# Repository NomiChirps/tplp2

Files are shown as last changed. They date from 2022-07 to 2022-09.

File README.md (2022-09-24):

# TPLP2

## Building

Install `bazel` (or `bazelisk`), `gcc-arm-none-eabi`, `arm-none-eabi-newlib`. Developed with `gcc-arm-12.1.0`.

```sh
# debug build
bazel build //tplp:firmware.uf2
# optimized build
bazel build //tplp:firmware.uf2 -c opt

# firmware blob is in bazel-bin
ls -lh bazel-bin/tplp/firmware.uf2
```

## TODO / Notes

- [ ] P1: motor speed pulsates while microstepping. fix this! it's important!
- [ ] don't like the pid algorithm from wikipedia. the proportional term is weird. let's find another one
- [ ] statically allocate all the instances of my hardware classes. we aren't going to be adding a third stepper motor at runtime, you dork.
  - [x] done for StepperMotor
- [ ] Milestone: Paper Tensioning
  - Be able to load paper and feed it forward and backward while maintaining correct tension.
  - [x] needs steppers working
  - [x] needs load cell persistently calibrated & installed
    - [x] save settings button
    - [x] manual calibration gui
    - [x] auto calibrate/zero button (& algorithm)
  - [ ] needs a PID loop with all the accoutrements
    - one loop watches printer roller encoder and controls CENTER of motor target positions
    - one loop watches load cell and controls DIFFERENCE between motor target positions
    - and two MORE loops watch motor target positions and controls motor speeds & directions. maybe those aren't pid though - something about a minimum jerk trajectory? idk.
    - this also means we need to actually install the encoder sooner rather than later.
    - i still want a mathematically sound PID tuning UI. or i guess procedure, if i expose everything in the new params ui.
  - hah, interesting thought... should we use some kind of online state estimation (Kalman filter???) to keep track of the relative radius of the rolls? observe that when moving the rollers at equal but opposite angular velocities, the roll with the greater radius causes the print roller to turn slightly in its direction while tension increases. when the radii are equal, tension would increase while the print roller stays motionless. ... if we can estimate this, would it even be useful? hmmmmmmmmmmmmmmmmmmmmmm
- [ ] I2cController doesn't fail gracefully when a read times out!
- [ ] Create a front panel UI (assignee: wembly :)
  - [ ] runtime stats / logging screen
  - [ ] (later) print status / job control / main screen ?
  - [x] remove the "home" screen, just use that left sidebar for everything. but also hide/delete it when not in use: to free up horizontal space on the screen and to conserve RAM.
  - [x] some kind of display for non-fatal errors. modal dialog box? little icon in the corner to tap on and expand? idk.
    - went with a simple modal
  - [x] manual motor control screen
  - [x] I2C bus scan
  - [x] virtual class interface for callbacks 'n' stuff
  - [x] Use [LVGL](https://lvgl.io)
- [ ] Get peripheral hardware running
  - [ ] Roller encoder
    - neglected to add this to the original hardware design ;(
  - [ ] Laser module (PWM control)
  - [ ] Mirror motor (PWM control; still needs a driver circuit)
  - [ ] Mirror optointerrupter
  - [ ] pinhole photodiode for self-calibration and/or self-test
  - [x] MicroSD card reader
    - we may want two. the one in the display is very difficult to access, so it's more suited to being the internal storage.
    - alternatively, forget using SD cards to upload and go ahead with the wi-fi interface, haha
      - an embedded target and a command-line client tool, in the same project? time for bazel to shine ~
  - [x] Stepper drivers
  - [x] HX711 load cell reader
  - [x] Shiny new front panel display + LVGL driver
  - [x] touchscreen input (SPI breakout)
  - [x] Sharp LCD display + LVGL driver
- [ ] Transfer electronics to a PCB with 12v supply when finalized.
- [ ] loadcell needs its own (shielded?) cable with really good clean connectors that don't jiggle

- 32-bit aligned reads and writes are atomic. It would be nice to take advantage of that and avoid some locking where possible.
  - update: yes indeed, i certainly have been getting sloppy about locking. will i regret it? time will tell.

### Nice to have

- [ ] bring parameter values back and save them in source control at some point. maybe do this automatically somehow (parse the startup log? simple, dirty, works)
- [ ] stepper driver: should coils be set to freewheel (LL) or short-brake (HH) at the top of each command cycle? maybe experiment with it.
- [ ] factory reset button (restoring all params to default, e.g. by deleting the config dir)
- [ ] fatal error handler to display the stack trace on the GUI before crashing
  - will require support from picolog. make sure picolog prevents the crashed task from proceeding, and has a watchdog or something to finish crashing the device if the fatal error handler doesn't finish in time.
- [ ] audit codebase for portMAX_DELAY, CHECK, etc. and make sure everything that can fail "gracefully", does.
- [ ] JTAG? is that a thing i can do?
- [ ] rename all the lvgl_driver.cc to have distinct module names for VLOG
- [ ] clear the display on boot. the random pixels look kinda cool but...
  - actually, no 'clear' command exists. best we can do is turn off the pixels (command 22h, pp.139), do a full memory write, and turn them back on.
- [ ] TSC2007 lvgl driver should debounce, buffer, and interpolate
- [ ] I2cController needs nonblocking operations, coalescing commands, general TLC
- [ ] hook up tft backlight pin and add an adjustable brightness setting (PWM)
- [ ] fix "bazel test //..." by adding target_compatible_with where appropriate
  - this may also involve fixing up rules_pico to make correct use of the defines PICO_NO_HARDWARE and PICO_ON_DEVICE
- [ ] generate & examine .map file for the firmware blob
- [ ] use bloaty to find things to trim off the firmware size
  - random forum post recommends copts "-ffunction-sections -fdata-sections" and ldopts "–gc-sections"
- [ ] Vendor all 3rd party libraries
- [ ] split out various things i'm proud of as their own librar(ies)
- [ ] write stress tests for SpiController/I2cController. lotsa tasks, lotsa devices, all hammering away

## Board configuration/pins

### Pinout / Peripherals

See `tplp/tplp_config.h` for pin and GPIO assignments.

| Bus  | Devices |
| ---- | --- |
| SPI0 | - |
| SPI1 | HX8357; SD Card |
| I2C0 | TSC2007 |
| I2C1 | - |

### Stepper driver ribbon cable layout

- Pin 1 (red) - ENA
- Pin 2 - IN1
- Pin 3 - IN2
- Pin 4 - IN3
- Pin 5 - IN4
- Pin 6 - ENB

### Load cell connector

- Pin 1 - Red - E+
- Pin 2 - Black - E-
- Pin 3 - Green - A-
- Pin 4 - White - A+

## Debugging

Note that USB serial stdio is not available while debugging because pico-debug uses the USB port.

### Setup

1. You will need to have the standard GNU autotools/configure/make toolchain installed on your system, for building OpenOCD.
1. Make sure you'll have the appropriate permissions to access the pico-debug CMSIS-DAP USB device; this can be accomplished by adding a [udev rule](https://github.com/openocd-org/openocd/blob/master/contrib/60-openocd.rules) and adding yourself to the `plugdev` group mentioned in that rule (or edit the rule to use a different group).
1. If using Visual Studio Code, install the "Cortex-Debug" extension.
1. If not using Visual Studio Code, build OpenOCD: `cd third_party/openocd; bazel build //:openocd`. This will download and compile the appropriate version of OpenOCD within the Bazel sandbox, leaving the binaries in `third_party/openocd/bazel-bin/external/openocd/openocd/bin/openocd` and the scripts dir in `third_party/openocd/bazel-bin/external/openocd/openocd/share/openocd/scripts`. Isn't it funny how if you say openocd enough times it doesn't sound like a real word anymore?

### To debug under VSCode

See also: https://github.com/majbthrd/pico-debug/blob/master/howto/vscode1.md

1. Put Pico into bootloader mode (reset while holding BOOTSEL).
1. Run the `flash pico-debug` task in VSCode. This downloads a prebuilt pico-debug image and copies it to the device. Pico is now running the debugger on core 1.
1. Build tplp in debug mode by running the `[debug] build` task.
1. Launch the debug configuration in VSCode ("Run and Debug" tab). This is defined in `.vscode/launch.json`. This will also download and build OpenOCD first, if it hasn't already.
1. The program should automatically be loaded onto the Pico and start running in the debugger.
1. You can restart the program freely, but ending the debug session means you'll need to reflash pico-debug to start again.
   In order to make changes and restart, run the `[debug] build` task and then issue the `load` command in the debug console. Wait for the transfer to finish before hitting the Restart button (Ctrl+Shift+F5).

### To debug without IDE support

See also https://github.com/majbthrd/pico-debug/blob/master/howto/openocd.md.

1. Put Pico into bootloader mode (reset while holding BOOTSEL).
1. Run `bazel run //tools:flash-pico-debug`, which downloads a prebuilt [pico-debug](https://github.com/majbthrd/pico-debug) binary and copies it to the device. Pico is now running the debugger on core 1.
1. Start the OpenOCD server: `third_party/openocd/bazel-bin/external/openocd/openocd/bin/openocd -s third_party/openocd/bazel-bin/external/openocd/openocd/bin/openocd -f interface/cmsis-dap.cfg -f target/rp2040-core0.cfg -c "transport select swd" -c "adapter speed 4000"`. It should connect to the Pico and wait for commands.
1. Build tplp in debug mode: `bazel build --config=picodebug //tplp:firmware.elf`
1. Start GDB: `arm-none-eabi-gdb bazel-bin/tplp/firmware.elf`.
1. Connect GDB to OpenOCD: `(gdb) target remote localhost:3333`.
1. Load the target into flash: `(gdb) load`.
1. Start it: `(gdb) monitor reset init`, `(gdb) continue`.

## Reference Materials

- [RP2040 Datasheet](https://datasheets.raspberrypi.com/rp2040/rp2040-datasheet.pdf) (the good stuff)
- [Raspberry Pi Pico SDK PDF docs](https://datasheets.raspberrypi.com/pico/raspberry-pi-pico-c-sdk.pdf) (more info than the HTML version)
- [Raspberry Pi Pico SDK HTML docs](https://raspberrypi.github.io/pico-sdk-doxygen/) (bare API reference)
- [Raspberry Pi Pico Datasheet](https://datasheets.raspberrypi.com/pico/pico-datasheet.pdf)
- [Getting started with Raspberry Pi Pico](https://datasheets.raspberrypi.com/pico/getting-started-with-pico.pdf)
- [What is the proper way to debounce a GPIO input?](https://raspberrypi.stackexchange.com/questions/118349/what-is-the-proper-way-to-debounce-a-gpio-input)
- [Hardware Design with the RP2040](https://www.mouser.com/pdfDocs/hardware-design-with-rp2040.pdf)
- [FreeRTOS Kernel Quick Start Guide](https://www.freertos.org/FreeRTOS-quick-start-guide.html)
- [FreeRTOS RP2040 SMP demos](https://www.freertos.org/smp-demos-for-the-raspberry-pi-pico-board.html)
- [Use Arduino Libraries with the Rasperry Pi Pico C/C++ SDK](https://www.hackster.io/fhdm-dev/use-arduino-libraries-with-the-rasperry-pi-pico-c-c-sdk-eff55c)
- [How to define and measure clock jitter](https://www.sitime.com/api/gated/AN10007-Jitter-and-measurement.pdf)
- [Bit Twiddling Hacks](http://graphics.stanford.edu/~seander/bithacks.html) (the one and only)

## todos whomst done

- [x] P0: finish making my type-safe fixpoint thing so i can implement the PROPERLY discretized pid algorithm from wikipedia
- [x] redesign manual stepper control UI to match the new API and to be easier to use
- [x] **P1: fix major stepper glitch when reversing direction**
- [x] P1: Okay we REALLY need to be able to dial the motor speed ALL the way down right next to zero. the pid loop is not happy otherwise.
- [x] FIXME: go through all my uses of __not_in_flash and add asserts to make sure they're actually doing that thing (addr < 0x1000000)
- [x] stepper timer interrupt isn't doing the right thing w.r.t. rearming the alarm. fix that. maybe make a template from the impl in paper_controller.
- [x] (!!!) steppers need to be able to go slower! a lot slower!
  - When hz is below the threshold, switch from DMA timer + DREQ to a timer interrupt (high priority, probably?)
- [x] Clean up the prototype electronics
  - [x] remember to power pico thru VSYS, not VBUS, to avoid potentially sending power upstream to the usb host
  - [x] supply 5V to HX711
  - [x] Add bus capacitors
- [x] fix all instances of std::setw(). it only sticks for one output field...
- [x] Begin() Setup() Init(), **PICK ONE**
- [x] UX Improvements
  - [x] fix everything in the ui being scrollable
  - [x] numeric display of load cell value & raw value
  - [x] oops changed my mind about the load cell units. they're actually completely arbitrary.
- [x] need a thingy for persistently saving global parameters / preferences / whatever you wanna call em.
- [x] alright fine let's get StrCat in here sheeeeesh
- [x] SpiController could use improvement - we're not getting full utilization of the bus
  - verdict: use the new DmaController with nonblocking operations where possible, and that's gonna be good enough.
- [x] Load cell time!
  - [x] hx711 pio driver
  - [x] gui for monitoring & calibration
  - [x] print some brackets to calibrate it against my digital scale
- [x] put the load cell period (100ms) in constants.h
- [x] read about the hardware interpolators in rp2040
  - does what it says on the tin. good for linear scaling, affine texture mapping, that kinda thing.
- [x] Mission: DMA 9000
  - see new ideas in tplp/bus/dma.h !!!
  - SpiController needs to take advantage of the new Action stuff to be more nonblocking, and actually make use of the DmaManager queue.
    - to manage CS easily we might need before-Actions as well as after-Actions!
  - I2cController needs... uh... idk i don't want to look at it right now
  - after action report: the new ideas in tplp/bus/dma.h were waaaay too complicated and not actually a performance improvement. went back to the now-current implementation and fixed up SpiController/I2cController to take advantage of its async features.
    - I NEVER WANT TO LOOK AT DMA AGAIN >:(
- [x] Install jumpers on the stepper drivers (to configure internal 5v power supply)
- [x] figure out who's allowed to call xTaskCreate. centralize it.
- [x] forget the std::duration stuff.. really not worth the hassle.
- [x] rename SpiManager -> SpiController
- [x] insert appropriate delays in TSC2007 read cycle; we have noise problems
- [x] consider removing all deletions of FreeRTOS objects and switching to heap_1
  - I considered it. it's not gonna happen
- [x] move/redirect config headers to a config/ dir
- [x] (?!) display fails self-test during startup if usb-serial output not present
  - the issue was it needed some time to boot up after poweron before accepting commands
- [x] LVGL driver for HX8357
- [x] HX8357 self test :)
- [x] rework SpiController again again; it should be able to suport full duplex. instead of sendevent/receiveevent, let's have transferevent(naming???) which specifies optionally both buffers. I GUESS???? if both are specified, they would necessarily have to be the same length!
- [x] get a compile_commands going for //simulator
- [x] have FreeRTOS and LVGL running together in a simulator mode on the host, for UI development (and unit testing?!)
- [x] fix lvgl+simulator so it doesn't build SDL2 twice
- [x] it is time to reorganize the directory structure again
  - we've got /openocd, /lib, /picolog, /tplp... too many different kinds of things at the top level
- [x] bazel build for OpenOCD binary!
- [x] WONTFIX: run blaze with layering_check; but need to do it on Linux because it requires CC=clang. might also need to add clang support to rules_pico.
  - this definitely isn't gonna happen. it needs support from the toolchain definition and i don't want to research how to implement that.
- [x] fix compile_commands extraction, again (problem with lvgl build? maybe strip_include_prefix works correctly on Linux?)
- [x] Why are we spending so much time in Tmr Svc?
  - it's actually not that much time now, without SMP.
- [x] please let's replace tplp_assert() with CHECK(), CHECK_NOTNULL(), etc. likewise DebugLog() -> LOG(INFO), VLOG(1), etc.
  - Implemented "picolog" and broke it out into a library :)
- [x] switch to Linux because wow gosh heckie does windows suck for this kind of development
- [x] create a lint.sh or something. to cover cc and bzl files (using Trunk vscode extension)
- [x] spend a week fruitlessly debugging instability between FreeRTOS-SMP + pico-sdk before giving up on SMP in disgust. at least I learned a lot and ironed out a few other issues along the way.
- [x] vApplicationGetIdleTaskMemory mystery: why doesn't my definition clash with the rp2040 port's in idle_task_static_memory.c?
  - ah. because i needed alwayslink=1 in FreeRTOS. it's fine though, we don't need to add it. the local definition gets linked in just fine.
- [x] (vanity) rename FreeRTOS or FreeRTOS-Kernel to the same thing, so we can say e.g. "@FreeRTOS" instead of "@FreeRTOS-Kernel//:FreeRTOS"
- [x] Tune FreeRTOS
  - The verdict: we'll be using non-SMP with preemption. If we need the second core for something, we'll put it there manually.
  - [x] enable SMP/multicore
    - turns out this was a terrible idea.
  - [x] audit FreeRTOSConfig.h
  - [x] (friendship ended with Arduino) audit Arduino compat libraries for blocking delays?
  - [x] (friendship ended with Arduino) use scope to verify reliability in the presence of Arduino libs
  - [x] write configASSERT handler (use the NeoPixel LED?)
- [x] use the genrule() trick to finally encapsulate FreeRTOS headers
- [x] use DMA for the Sharp LCD driver, just for funsies
- [x] figure out how to track TODO/FIXME/XXX in IDE
- [x] organize source code under src/ (I changed my mind later)
- [x] (it's not possible, i decided) refer to FreeRTOS headers with a prefix, if possible (actually it is)
- [x] Make sure we're not using floating point math anywhere (including dependencies): discovered via std::unordered_map that we panic if any floating point math is used
- [x] Reset to the bootloader without touching the board: magic 1200 baud connection
- [x] Get FreeRTOS running
- [x] Bazel-ify the build

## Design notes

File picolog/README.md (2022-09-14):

# Picolog

Experimental, ambitiously-named [glog-style](https://github.com/google/glog) C++ logging library for the Raspberry Pi Pico under gcc + pico-sdk + FreeRTOS.

Logs are collected in a FreeRTOS queue and flushed to the output asynchronously; unless the FreeRTOS scheduler hasn't been started yet, in which case they are processed immediately.

Not tested with FreeRTOS-SMP or with pico_multicore.

Add the `-mpoke-function-name` compiler flag to get function names in the backtrace for fatal errors.

## Wishlist

- [ ] okay it might be time to move the non-logging ABSL ripoff stuff to somewhere else? or just consider it a PORT of parts of absl??
- [ ] LOG_EVERY
- [ ] track the maximum timestamp as logs are flushed, and make it visually obvious if it ever goes backwards (due to a task being interrupted while logging)
- [ ] arena storage for the non-inlined StatusRep. or maybe we can get rid of it and require that the message be a compile-time constant...? or even better, provide a special case to make that path alloc-free.
- Maybe have a separate task handling FATAL errors so it can be given the highest priority.
- [ ] arena storage for LogMessageData to avoid malloc (still requires mutex)
- [ ] DCHECK
- [ ] LOG level toggles at runtime, maybe per-task and/or per-module
- [ ] ^-- leads to: unit/etc tests
- [ ] Trap hard faults so we can get stack traces for a nullptr dereference :)
  - https://github.com/yocto-8/yocto-8/blob/main/src/arch/pico/extmem/faulthandler.cpp#L12
  - https://forums.raspberrypi.com/viewtopic.php?t=318745
- [ ] support other log targets than stdout, e.g. flash, sd, or custom.
- [x] StatusOr
- [x] support immediate logging before the FreeRTOS scheduler starts
- [x] soften the hard dependency on pico-sdk, so we can run tests and use it in the simulator, with FreeRTOS's posix port
- [x] Status object and CHECK_OK
- [x] per-file VLOG toggles at compile time (use a constexpr function for string comparison with `__FILE__`, probably)
- [x] test for VLOG_IS_ON

## Hard Fault recovery, maybe

See section B1.5.6 of the ARMv6-M reference manual.

When pushing context to the stack, the hardware saves eight 32-bit words, comprising xPSR, ReturnAddress(), LR(R14), R12, R3, R2, R1, and R0.

B1.5.8 Exception return behavior
| EXC_RETURN | Behavior |
| - | - |
| 0xFFFFFFF1 | Return to Handler Mode. Exception return gets state from the Main stack. On return execution uses the Main Stack. |
| 0xFFFFFFF9 | Return to Thread Mode. Exception return gets state from the Main stack. On return execution uses the Main Stack. |
| 0xFFFFFFFD | Return to Thread Mode. Exception return gets state from the Process stack. On return execution uses the Process Stack. |

In the case of a memory fault when recovering the xPSR, if the EXC_RETURN value indicates that the exception return:

- must use the Main stack, SP_main, a lockup at HardFault priority occurs.
- must use the Process stack, SP_process, a Pending HardFault exception is generated

hmmmm

- what is xPSR?
- exception return operation checks SCR.SLEEPONEXIT
- pg. 200 is the handler pseudocode we must satisfy in order to restore into a normal stack
- also check out the freertos rp2040 port implementation!! maybe we can crib most of it off that.

"In ARMv6-M, faults are considered fatal. The only fault status information provided on entry to the HardFault
handler is the EXC_RETURN value, that indicates whether the fault originated from Thread or Handler mode. The
fault handler returns according to the rules defined in ReturnAddress(), see Exception entry behavior on
page B1-196 for details"

"While ARMv6-M does not provide
fault status information to the HardFault handler, it does permit the handler to perform an exception return and
continue execution, in cases where software has the ability to recover from the fault situation"

" Setting the AIRCR.SYSRESETREQ control bit to 1 requests a reset by an
external system resource. The system components that are reset by this request are IMPLEMENTATION DEFINED. A
Local reset is required as part of a system reset request.
Setting the SYSRESETREQ bit to 1 does not guarantee that the reset takes place immediately. A typical code
sequence to synchronize reset following a write to the relevant control bit is:"

```asm
     DSB;
Loop B Loop;
```

-> Could we have the task jump from the faulting instruction to a different function instead? One that calls vTaskSuspend(nullptr) forever. See: vPortStartFirstTask().

http://fastbitlab.com/free-rtos/ has some hints.

## Acknowledgements

Portions of this code are derived from the ABSL library under the terms of the [Apache 2.0 license](https://www.apache.org/licenses/LICENSE-2.0).

```legalese
Copyright 2020 The Abseil Authors.

Licensed under the Apache License, Version 2.0 (the "License");
you may not use this file except in compliance with the License.
You may obtain a copy of the License at

     https://www.apache.org/licenses/LICENSE-2.0

Unless required by applicable law or agreed to in writing, software
distributed under the License is distributed on an "AS IS" BASIS,
WITHOUT WARRANTIES OR CONDITIONS OF ANY KIND, either express or implied.
See the License for the specific language governing permissions and
limitations under the License.
```

Portions of this code are derived from Google's glog library, the license notice of which is reproduced below:

```legalese
Copyright (c) 2008, Google Inc.
All rights reserved.

Redistribution and use in source and binary forms, with or without
modification, are permitted provided that the following conditions are
met:

    * Redistributions of source code must retain the above copyright
notice, this list of conditions and the following disclaimer.
    * Redistributions in binary form must reproduce the above
copyright notice, this list of conditions and the following disclaimer
in the documentation and/or other materials provided with the
distribution.
    * Neither the name of Google Inc. nor the names of its
contributors may be used to endorse or promote products derived from
this software without specific prior written permission.

THIS SOFTWARE IS PROVIDED BY THE COPYRIGHT HOLDERS AND CONTRIBUTORS
"AS IS" AND ANY EXPRESS OR IMPLIED WARRANTIES, INCLUDING, BUT NOT
LIMITED TO, THE IMPLIED WARRANTIES OF MERCHANTABILITY AND FITNESS FOR
A PARTICULAR PURPOSE ARE DISCLAIMED. IN NO EVENT SHALL THE COPYRIGHT
OWNER OR CONTRIBUTORS BE LIABLE FOR ANY DIRECT, INDIRECT, INCIDENTAL,
SPECIAL, EXEMPLARY, OR CONSEQUENTIAL DAMAGES (INCLUDING, BUT NOT
LIMITED TO, PROCUREMENT OF SUBSTITUTE GOODS OR SERVICES; LOSS OF USE,
DATA, OR PROFITS; OR BUSINESS INTERRUPTION) HOWEVER CAUSED AND ON ANY
THEORY OF LIABILITY, WHETHER IN CONTRACT, STRICT LIABILITY, OR TORT
(INCLUDING NEGLIGENCE OR OTHERWISE) ARISING IN ANY WAY OUT OF THE USE
OF THIS SOFTWARE, EVEN IF ADVISED OF THE POSSIBILITY OF SUCH DAMAGE.
```

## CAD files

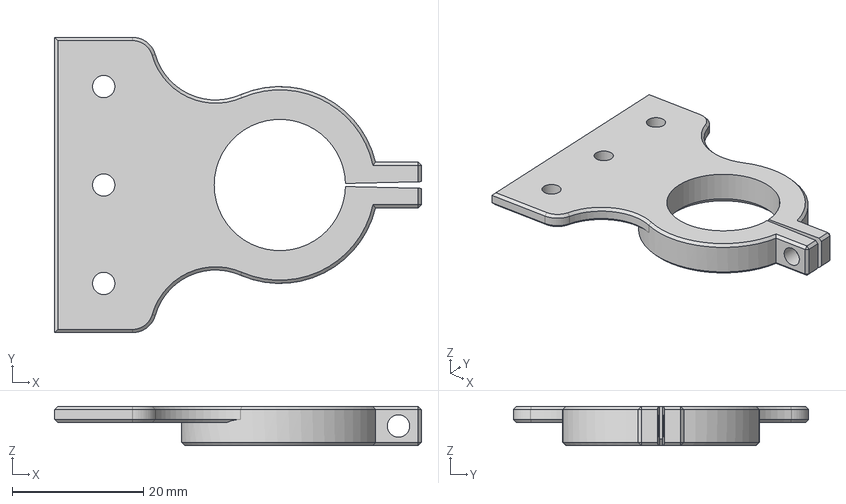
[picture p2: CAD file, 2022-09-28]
cad/Encoder mount v4.step
55.9 x 45.0 x 6.00 mm

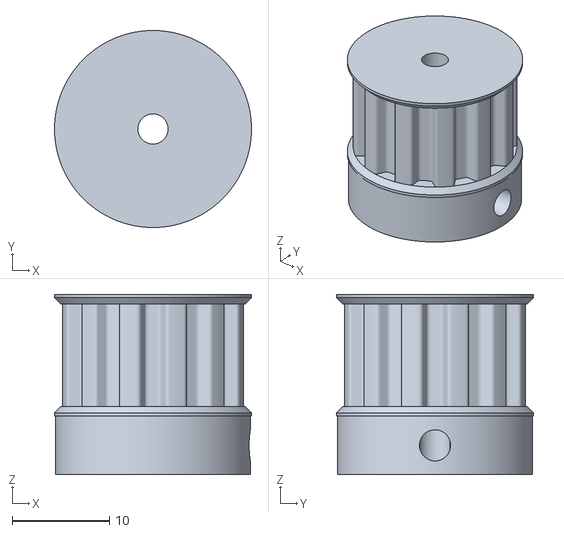
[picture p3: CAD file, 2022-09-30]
cad/pulleys/dcmotor-12.stl
20.2 x 20.2 x 18.5

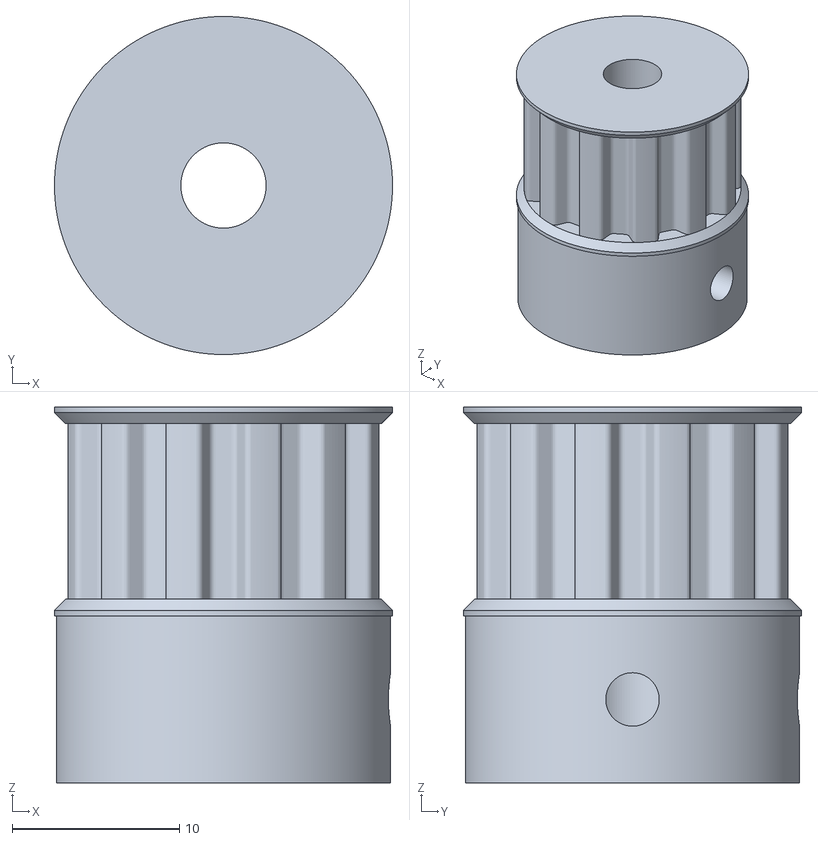
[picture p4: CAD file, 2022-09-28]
cad/pulleys/steppermotor-12.stl
20.2 x 20.2 x 22.5

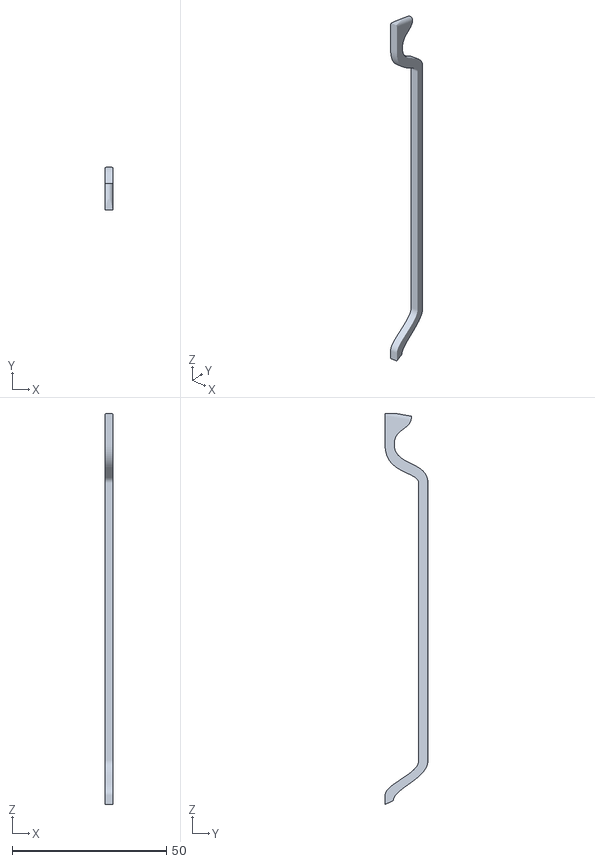
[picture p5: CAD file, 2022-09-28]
cad/spool rib.stl
2.60 x 13.9 x 126.8

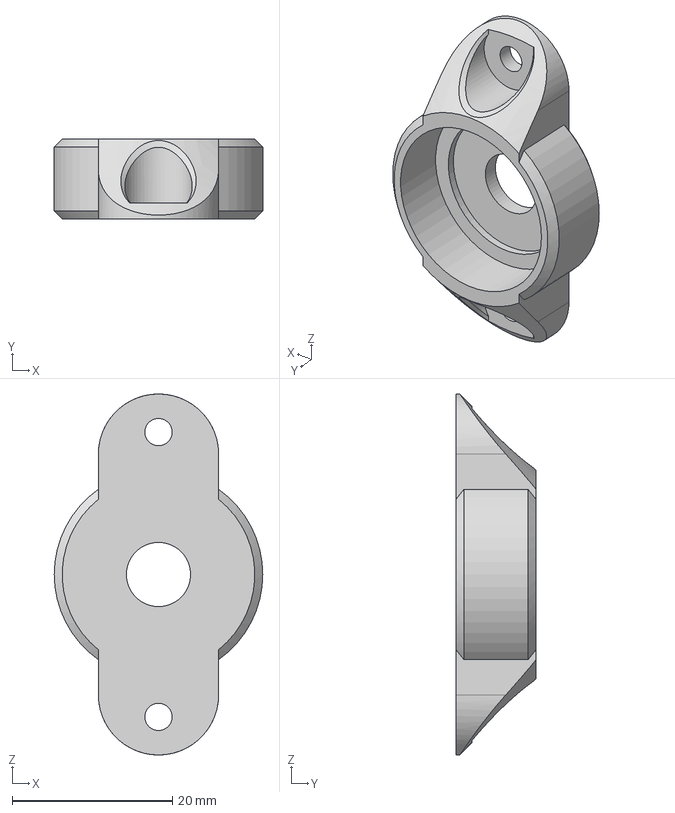
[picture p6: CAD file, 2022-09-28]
cad/bearing seat 608 v3.step
26.0 x 10.0 x 45.0 mm

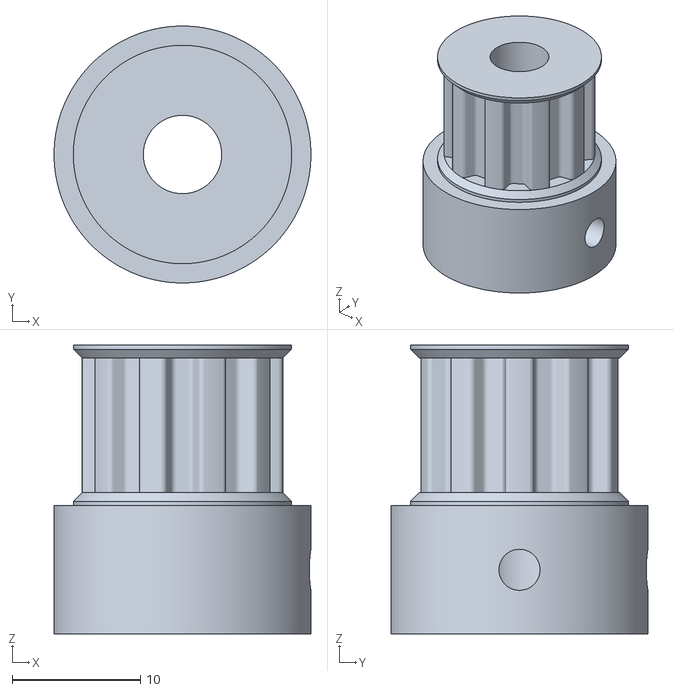
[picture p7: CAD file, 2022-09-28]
cad/pulleys/encoder-10.stl
20.0 x 20.0 x 22.5

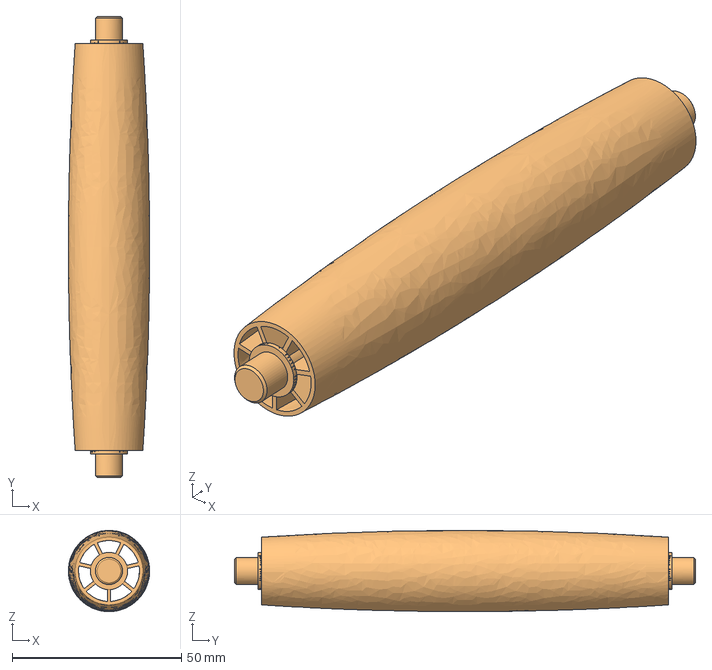
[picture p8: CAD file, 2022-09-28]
cad/guide roller v7.step
24.0 x 136.0 x 24.0 mm
bearing pin 608 x 2

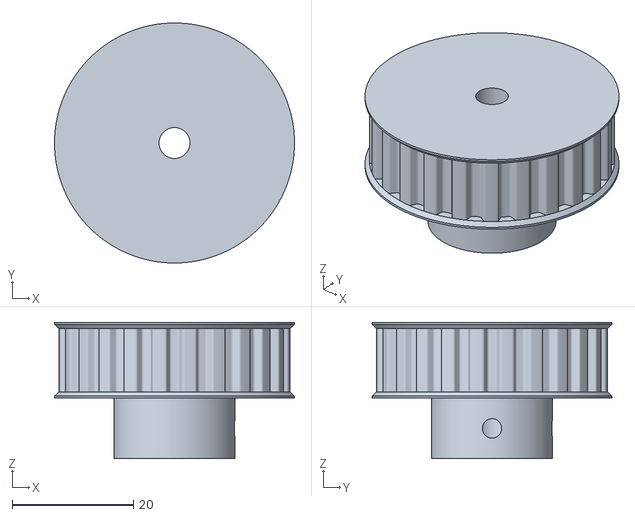
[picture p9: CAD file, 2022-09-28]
cad/pulleys/steppermotor-24.stl
39.6 x 39.6 x 22.5

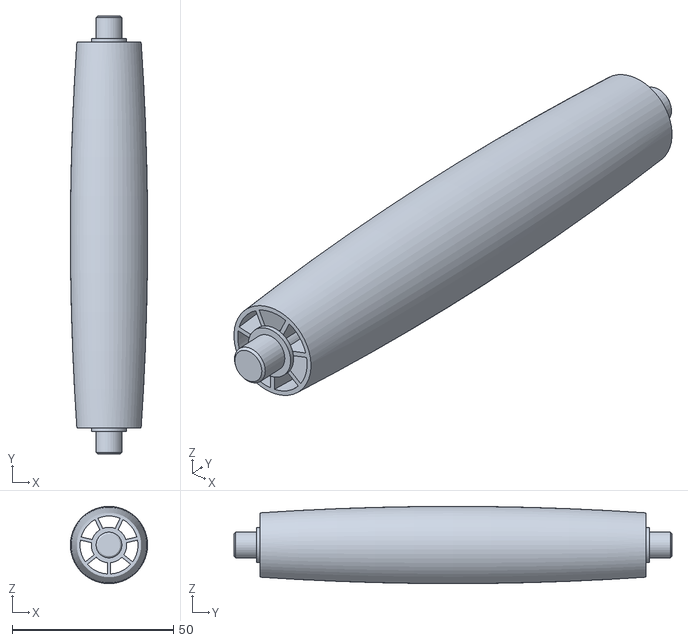
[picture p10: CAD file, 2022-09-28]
cad/guide roller.stl
24.0 x 136.0 x 24.0

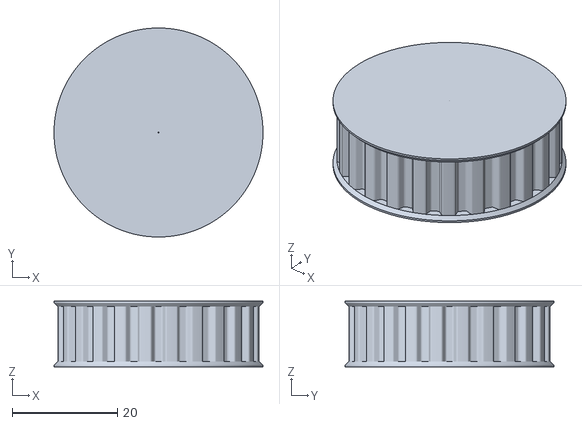
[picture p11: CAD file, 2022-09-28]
cad/pulleys/bare-24.stl
39.6 x 39.6 x 12.5

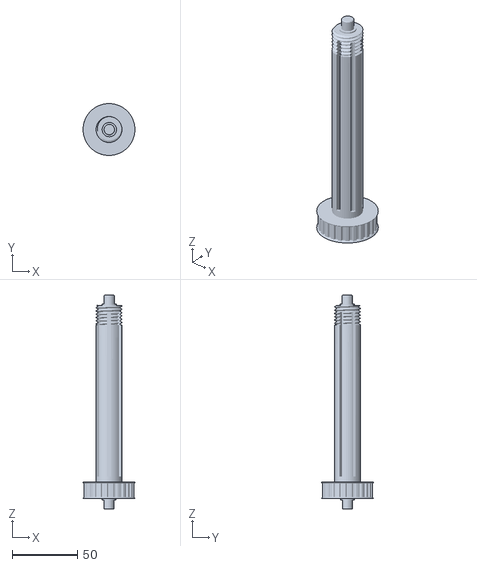
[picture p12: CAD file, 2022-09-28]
cad/spool body.stl
39.6 x 39.6 x 163.5

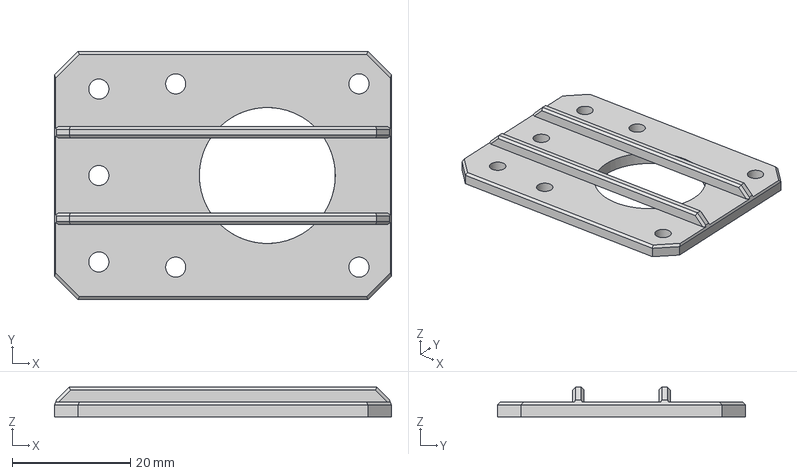
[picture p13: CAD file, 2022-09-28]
cad/Stepper mount v3.step
57.0 x 42.0 x 5.00 mm

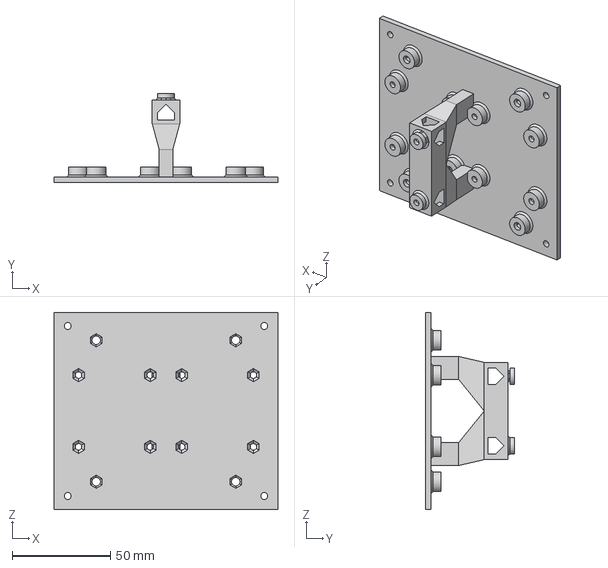
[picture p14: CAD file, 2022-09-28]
cad/stepper driver enclosure v4.step
114.0 x 45.5 x 100.5 mm

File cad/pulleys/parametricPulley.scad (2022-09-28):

// Parametric Pulley with multiple belt profiles
// by droftarts January 2012
// updated and changed by Oscar January 2018 (https://www.thingiverse.com/0scar/about)

// Based on pulleys by:
// http://www.thingiverse.com/thing:11256 by me!
// https://github.com/prusajr/PrusaMendel by Josef Prusa
// http://www.thingiverse.com/thing:3104 by GilesBathgate
// http://www.thingiverse.com/thing:2079 by nophead

// dxf tooth data from http://oem.cadregister.com/asp/PPOW_Entry.asp?company=915217&elementID=07807803/METRIC/URETH/WV0025/F
// pulley diameter checked and modelled from data at http://www.sdp-si.com/D265/HTML/D265T016.html

/**
 * @name Pulley
 * @category Printed
 * @using 1 x m3 nut, normal or nyloc
 * @using 1 x m3x10 set screw or 1 x m3x8 grub screw
 */

// ------------------------
// Idler profile parameters
// ------------------------
number_of_teeth = 60; // [10:100]
profile = 12; // [1:MXL, 2:40DP, 3:XL, 4:H, 5:T2.5, 6:T5, 7:T10, 8:AT5, 9:HTD_3mm, 10:HTD_5mm, 11:HTD_8mm, 12:GT2_2mm, 13:GT2_3mm, 14:GT2_5mm]
motor_shaft_diameter = 8.2; // (in mm)
// Added to the diameter.
motor_shaft_clearance = 0.1;
toothed_part_length = 6.2; // [3:30] (in mm)
base_height = 0; // [0:30] (in mm, 6 is typical)
base_diameter = 20;   // [10:50] (in mm)

// ---------------------------
// Idler & retainer parameters
// ---------------------------
belt_retainer = 1; // [0:No, 1:Yes]
retainer_height_p = 1.0; // [0.5:Tiny (0.5mm), 1:Small (1mm), 1.5:Normal (1.5mm), 2:Big (2mm), 3:Bigger (3mm), 4:Hudge (5mm)]
belt_idler = 1; // [0:No, 1:Yes]
// Height of idler flange over pulley. Set to same as base height if you want an idler but no pulley.
idler_height_p = 1.0; // [0.5:Tiny (0.5mm), 1:Small (1mm), 1.5:Normal (1.5mm), 2:Big (2mm), 3:Bigger (3mm), 4:Hudge (5mm)]

// ---------------
// Shaft fastening
// ---------------
screws_disposition = 3; // [0:None, 1:1 screw, 2:2 screws at 90deg, 3:3 screws at 120deg, 4:4 screws at 90deg]
nut_shape = 1; // [1:Hexagonal, 0:Square]
screw_profile = 4; // [0:M1, 1:M1.6, 2:M2, 3:M2.5, 4:M3, 5:M4, 6:M5, 7:M6]

// Distance between inner face of nut and shaft - can be negative - (in mm).
nut_shaft_distance = 1.2;

// Bolt head shape (0 is inactive) subtracts a bolt head sized hexagon for hexagon bolts
idler_bolt_option = 0; // [0:none, 1:M3, 2:M4, 3:M5, 4:M6, 5:M8, 6:M10, 7:M12, 8:custom] for custom: make changes below!

// Optional metal flange attachment (0 is inactive)
flange_option = 1;
flange_screw_profile = 5; // [0:M1, 1:M1.6, 2:M2, 3:M2.5, 4:M3, 5:M4, 6:M5, 7:M6]
flange_screws_disposition = 4; // [0:None, 1:1 screw, 2:2 screws at 180deg, 3:3 screws at 120deg, 4:4 screws at 90deg]
flange_screwoffset_radius = 26/2;
flange_diam = 32; // Set to zero to disable the flange to be sunk in the idler
flange_thickness = 3; // Set to zero to disable the flange to be sunk in the idler
flange_use_tap = 1; // Diameter is smaller when used for tapping, 0 to larger hole for easy fit


// --------------------------------------------------
// ADVANCED parameters for scaling tooth for good fit
// --------------------------------------------------
// To improve fit of belt to pulley, set the following constant.
// Decrease or increase by 0.1mm at a time. We are modelling the
// *BELT* tooth here, not the tooth on the pulley. Increasing the
// number will *decrease* the pulley tooth size. Increasing the
// tooth width will also scale proportionately the tooth depth,
// to maintain the shape of the tooth, and increase how far into
// the pulley the tooth is indented. Can be negative too!
additional_tooth_width = 0.2; //mm
// If you need more tooth depth than this provides, adjust the
// following constant. However, this will cause the shape of the
// tooth to change.
additional_tooth_depth = 0; //mm

// ------------------------------------
// Calculated parameters (do not alter)
// ------------------------------------
idler_height = (belt_idler==0 ? 0 : idler_height_p);
retainer_height = (belt_retainer==0 ? 0 : retainer_height_p);
//echo (str("Idler height\t= ",idler_height," mm"));
//echo (str("Retainer height\t= ",retainer_height," mm"));
no_of_nuts = screws_disposition;
nut_angle = no_of_nuts != 3 ? 90 : 120;
motor_shaft = motor_shaft_diameter + motor_shaft_clearance;
screw_diameters = [1, 1.6, 2, 2.5, 3, 4, 5, 6];
nut_widths = [2.5, 3.2, 4, 5, 5.5, 7, 8, 10];
nut_depths = [1, 1.3, 1.6, 2, 2.4, 3.2, 4.7, 5.2];
// bolthead size circ.[ none,    M3,    M4,   M5,    M6,    M8,   M10,   M12, custom]
bolt_head_diameters = [0.000, 6.010, 7.660, 8.79, 11.05, 14.38, 17.77, 20.03,  15.8]; // circle diameter, not width across flats!
bolt_head_heights =   [0.000, 2.125, 2.925, 3.65,  4.15,  5.45,  6.58,  7.68,   5.5];
screw_diameter = screw_diameters[screw_profile] + 0.2;
nut_width = nut_widths[screw_profile] + 0.2;
nut_depth = nut_depths[screw_profile] + 0.3;
bolt_head_diam = bolt_head_diameters[idler_bolt_option] + 0.2; // + 0.1-2 for tight fit
bolt_head_height = bolt_head_heights[idler_bolt_option] + 0.2;
screw_hole_sf = flange_use_tap == 1 ? 0.9 : 1.1; // 0.9 is the recommended value for taps of fine thread, 0.85 for coarse threads
flange_screw_diameter = screw_diameters[flange_screw_profile] * screw_hole_sf; 
flange_no_of_screws = flange_screws_disposition;
flange_screw_angle = flange_no_of_screws != 3 ? (flange_no_of_screws == 2 ? 180 : 90) : 120;

// --------------------
// Calculated constants
// --------------------
nut_elevation = base_height/2;
metric_nut_width_across_points = 2*((nut_width/2)/cos(30)); // This is needed for the nut trap
// The following set the pulley diameter for a given number of teeth
MXL_pulley_dia = tooth_spacing (2.032,0.254);
40DP_pulley_dia = tooth_spacing (2.07264,0.1778);
XL_pulley_dia = tooth_spacing (5.08,0.254);
H_pulley_dia = tooth_spacing (9.525,0.381);
T2_5_pulley_dia = tooth_spaceing_curvefit (0.7467,0.796,1.026);
T5_pulley_dia = tooth_spaceing_curvefit (0.6523,1.591,1.064);
T10_pulley_dia = tooth_spacing (10,0.93);
AT5_pulley_dia = tooth_spaceing_curvefit (0.6523,1.591,1.064);
HTD_3mm_pulley_dia = tooth_spacing (3,0.381);
HTD_5mm_pulley_dia = tooth_spacing (5,0.5715);
HTD_8mm_pulley_dia = tooth_spacing (8,0.6858);
GT2_2mm_pulley_dia = tooth_spacing (2,0.254);
GT2_3mm_pulley_dia = tooth_spacing (3,0.381);
GT2_5mm_pulley_dia = tooth_spacing (5,0.5715);
// The following calls the pulley creation part, and passes the pulley diameter and tooth width to that module
if ( profile == 1 ) {pulley("MXL" , MXL_pulley_dia , 0.508 , 1.321 ); }
if ( profile == 2 ) {pulley("40 D.P." , 40DP_pulley_dia , 0.457 , 1.226 ); }
if ( profile == 3 ) {pulley("XL" , XL_pulley_dia , 1.27, 3.051 ); }
if ( profile == 4 ) {pulley("H" , H_pulley_dia ,1.905 , 5.359 ); }
if ( profile == 5 ) {pulley("T2.5" , T2_5_pulley_dia , 0.7 , 1.678 ); }
if ( profile == 6 ) {pulley("T5" , T5_pulley_dia , 1.19 , 3.264 ); }
if ( profile == 7 ) {pulley("T10" , T10_pulley_dia , 2.5 , 6.13 ); }
if ( profile == 8 ) {pulley("AT5" , AT5_pulley_dia , 1.19 , 4.268 ); }
if ( profile == 9 ) {pulley("HTD 3mm" , HTD_3mm_pulley_dia , 1.289 , 2.27 ); }
if ( profile == 10 ){pulley("HTD 5mm" , HTD_5mm_pulley_dia , 2.199 , 3.781 ); }
if ( profile == 11 ){pulley("HTD 8mm" , HTD_8mm_pulley_dia , 3.607 , 6.603 ); }
if ( profile == 12 ){pulley("GT2 2mm" , GT2_2mm_pulley_dia , 0.764 , 1.494 ); }
if ( profile == 13 ){pulley("GT2 3mm" , GT2_3mm_pulley_dia , 1.169 , 2.31 ); }
if ( profile == 14 ){pulley("GT2 5mm" , GT2_5mm_pulley_dia , 1.969 , 3.952 ); }

// ---------
// Functions
// ---------
function tooth_spaceing_curvefit (b,c,d)
  = ((c * pow(number_of_teeth,d)) / (b + pow(number_of_teeth,d))) * number_of_teeth ;

function tooth_spacing(tooth_pitch,pitch_line_offset)
  = (2*((number_of_teeth*tooth_pitch)/(3.14159265*2)-pitch_line_offset)) ;

// ================================================================================
// Main Module
// ================================================================================
module pulley( belt_type , pulley_OD , tooth_depth , tooth_width ){
  echo (str("Belt type = ",belt_type,"; Number of teeth = ",number_of_teeth,"; Pulley Outside Diameter = ",pulley_OD,"mm "));
  tooth_distance_from_centre = sqrt( pow(pulley_OD/2,2) - pow((tooth_width+additional_tooth_width)/2,2));
  tooth_width_scale = (tooth_width + additional_tooth_width ) / tooth_width;
  tooth_depth_scale = ((tooth_depth + additional_tooth_depth ) / tooth_depth) ;

  difference(){   
    translate([0,0,idler_height]){
      union(){
        //base
        if (( base_height < 2 ) && (no_of_nuts > 0)){ 
          if (base_height != 0){
            echo ("CAN'T DRAW PULLEY BASE, HEIGHT LESS THAN 2!!!"); 
          }
        } else {
          translate([0,0,-idler_height]){
            cylinder(d=base_diameter, h=base_height, $fn=base_diameter*20, center=false);
          }
        }
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

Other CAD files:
cad/Encoder mount.stl
cad/pulleys/encoder-12.stl
cad/bearing seat 608.stl
cad/stepper driver enclosure.stl
cad/Stepper mount.stl
cad/spool nut.stl

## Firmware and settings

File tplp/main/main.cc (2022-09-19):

#include <cstdio>

#include "FreeRTOS/FreeRTOS.h"
#include "FreeRTOS/task.h"
#include "tplp/config/hw.h"
#include "tplp/config/tasks.h"
#include "tplp/main/startup.h"

#if LIB_PICO_STDIO_USB
#include "pico/stdio_usb.h"
#endif
#if LIB_PICO_STDIO_UART
#include "hardware/gpio.h"
#include "hardware/timer.h"
#include "pico/stdio_uart.h"
#endif

int main() {
#if LIB_PICO_STDIO_USB
  stdio_usb_init();
#endif
#if LIB_PICO_STDIO_UART
  stdio_uart_init_full(uart0, 115200, tplp::Pins::UART0_TX, -1);
  // Invert UART signal to be compatible with RS232.
  gpio_set_outover(tplp::Pins::UART0_TX, GPIO_OVERRIDE_INVERT);
  busy_wait_ms(100);
#endif

  // TODO: add a build timestamp and version line at bootup
  // printf("tplp2 built %s at %s", TPLP_BUILD_TIMESTAMP, TPLP_VERSION_ID);
  printf("tplp2 boot. TODO: add a build timestamp\n");

  xTaskCreate(&tplp::StartupTask, "STARTUP", tplp::TaskStacks::kStartup,
              nullptr, tplp::TaskPriorities::kStartup, nullptr);
  vTaskStartScheduler();
  panic("scheduler died :(");

  return 1;
}

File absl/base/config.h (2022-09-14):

//
// Copyright 2017 The Abseil Authors.
//
// Licensed under the Apache License, Version 2.0 (the "License");
// you may not use this file except in compliance with the License.
// You may obtain a copy of the License at
//
//      https://www.apache.org/licenses/LICENSE-2.0
//
// Unless required by applicable law or agreed to in writing, software
// distributed under the License is distributed on an "AS IS" BASIS,
// WITHOUT WARRANTIES OR CONDITIONS OF ANY KIND, either express or implied.
// See the License for the specific language governing permissions and
// limitations under the License.
//
// -----------------------------------------------------------------------------
// File: config.h
// -----------------------------------------------------------------------------
//
// This header file defines a set of macros for checking the presence of
// important compiler and platform features. Such macros can be used to
// produce portable code by parameterizing compilation based on the presence or
// lack of a given feature.
//
// We define a "feature" as some interface we wish to program to: for example,
// a library function or system call. A value of `1` indicates support for
// that feature; any other value indicates the feature support is undefined.
//
// Example:
//
// Suppose a programmer wants to write a program that uses the 'mmap()' system
// call. The Abseil macro for that feature (`ABSL_HAVE_MMAP`) allows you to
// selectively include the `mmap.h` header and bracket code using that feature
// in the macro:
//
//   #include "absl/base/config.h"
//
//   #ifdef ABSL_HAVE_MMAP
//   #include "sys/mman.h"
//   #endif  //ABSL_HAVE_MMAP
//
//   ...
//   #ifdef ABSL_HAVE_MMAP
//   void *ptr = mmap(...);
//   ...
//   #endif  // ABSL_HAVE_MMAP

#ifndef ABSL_BASE_CONFIG_H_
#define ABSL_BASE_CONFIG_H_

// Included for the __GLIBC__ macro (or similar macros on other systems).
#include <limits.h>

#ifdef __cplusplus
// Included for __GLIBCXX__, _LIBCPP_VERSION
#include <cstddef>
#endif  // __cplusplus

// ABSL_INTERNAL_CPLUSPLUS_LANG
//
// MSVC does not set the value of __cplusplus correctly, but instead uses
// _MSVC_LANG as a stand-in.
// https://docs.microsoft.com/en-us/cpp/preprocessor/predefined-macros
//
// However, there are reports that MSVC even sets _MSVC_LANG incorrectly at
// times, for example:
// https://github.com/microsoft/vscode-cpptools/issues/1770
// https://reviews.llvm.org/D70996
//
// For this reason, this symbol is considered INTERNAL and code outside of
// Abseil must not use it.
#if defined(_MSVC_LANG)
#define ABSL_INTERNAL_CPLUSPLUS_LANG _MSVC_LANG
#elif defined(__cplusplus)
#define ABSL_INTERNAL_CPLUSPLUS_LANG __cplusplus
#endif

#if defined(__APPLE__)
// Included for TARGET_OS_IPHONE, __IPHONE_OS_VERSION_MIN_REQUIRED,
// __IPHONE_8_0.
#include <Availability.h>
#include <TargetConditionals.h>
#endif

#include "absl/base/options.h"
#include "absl/base/policy_checks.h"

// Abseil long-term support (LTS) releases will define
// `ABSL_LTS_RELEASE_VERSION` to the integer representing the date string of the
// LTS release version, and will define `ABSL_LTS_RELEASE_PATCH_LEVEL` to the
// integer representing the patch-level for that release.
//
// For example, for LTS release version "20300401.2", this would give us
// ABSL_LTS_RELEASE_VERSION == 20300401 && ABSL_LTS_RELEASE_PATCH_LEVEL == 2
//
// These symbols will not be defined in non-LTS code.
//
// Abseil recommends that clients live-at-head. Therefore, if you are using
// these symbols to assert a minimum version requirement, we recommend you do it
// as
//
// #if defined(ABSL_LTS_RELEASE_VERSION) && ABSL_LTS_RELEASE_VERSION < 20300401
// #error Project foo requires Abseil LTS version >= 20300401
// #endif
//
// The `defined(ABSL_LTS_RELEASE_VERSION)` part of the check excludes
// live-at-head clients from the minimum version assertion.
//
// See https://abseil.io/about/releases for more information on Abseil release
// management.
//
// LTS releases can be obtained from
// https://github.com/abseil/abseil-cpp/releases.
#undef ABSL_LTS_RELEASE_VERSION
#undef ABSL_LTS_RELEASE_PATCH_LEVEL

// Helper macro to convert a CPP variable to a string literal.
#define ABSL_INTERNAL_DO_TOKEN_STR(x) #x
#define ABSL_INTERNAL_TOKEN_STR(x) ABSL_INTERNAL_DO_TOKEN_STR(x)

// -----------------------------------------------------------------------------
// Abseil namespace annotations
// -----------------------------------------------------------------------------
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

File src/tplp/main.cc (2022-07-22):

#include <chrono>
#include <cstdio>

#include "FreeRTOS.h"
#include "hardware/gpio.h"
#include "hardware/pio.h"
#include "hardware/spi.h"
#include "pico/bootrom.h"
#include "pico/stdlib.h"
#include "queue.h"
#include "src/lib/SharpLCD/SharpLCD.h"
#include "src/tplp/util.h"
#include "src/tplp/ws2812.h"
#include "task.h"

using std::chrono_literals::operator""ms;

extern "C" {

// FreeRTOS assertion failure handler
void vAssertCalled(const char *const file, unsigned long line) {
  printf("Assertion failed at: %s:%lu\n", file, line);
  // Leave interrupts enabled so we can still get back to the bootloader via
  // the USB serial magic thing.
  for (;;) {
  }
}

void FreeRTOS_ConfigureTimeForRunTimeStats() {}

unsigned long FreeRTOS_GetRunTimeCounterValue() {
  return to_us_since_boot(get_absolute_time());
}
}

namespace tplp {

struct Pins {
  static const uint LCD_CS = 8;
  static const uint SPI_SCLK = 18;
  static const uint SPI_MOSI = 19;
  static const uint NEOPIXEL = 16;
};

void lcd_task(void *) {
  SharpLCD display(spi0, Pins::SPI_SCLK, Pins::SPI_MOSI, Pins::LCD_CS);
  display.Begin();
  display.Clear();
  SharpLCD::FrameBuffer white = display.AllocateNewFrameBuffer();
  SharpLCD::FrameBuffer black = display.AllocateNewFrameBuffer();
  white.Clear(0);
  black.Clear(1);

  TaskHandle_t task = xTaskGetCurrentTaskHandle();
  std::function<void()> ready_isr = [task]() {
    BaseType_t higher_priority_task_woken;
    vTaskNotifyGiveFromISR(task, &higher_priority_task_woken);
    portYIELD_FROM_ISR(higher_priority_task_woken);
  };
  display.SetReadyISR(ready_isr);

  while (true) {
    display.DrawFrameBufferBlocking(white);
    ulTaskNotifyTake(false, portMAX_DELAY);
    display.DrawFrameBufferBlocking(black);
    ulTaskNotifyTake(false, portMAX_DELAY);
  }
}

void led_task(void *) {
  const int LED_PIN = PICO_DEFAULT_LED_PIN;
  gpio_init(LED_PIN);
  gpio_set_dir(LED_PIN, GPIO_OUT);
  while (true) {
    gpio_put(LED_PIN, 1);
    vTaskDelay(as_ticks(200ms));
    gpio_put(LED_PIN, 0);
    vTaskDelay(as_ticks(200ms));
  }
}

void neopixel_task(void *) {
  // ws2812_program_init(PIO pio, uint sm, uint offset, uint pin, float freq,
  // bool rgbw)
}

void button_task(void *) {
  // xQueueReceive(button_queue, void *const pvBuffer, TickType_t xTicksToWait);
}

void stats_task(void *) {
  static char buf[1024];
  for (;;) {
    vTaskDelay(as_ticks(10'000ms));
    printf("-- FreeRTOS Stats --\n");
    vTaskGetRunTimeStats(buf);
    puts(buf);
    printf("--------------------\n");
    stdio_flush();
  }
}

int main() {
  stdio_init_all();
  printf("Hello!\n");

  xTaskCreate(&tplp::lcd_task, "lcd", 1024, nullptr, 1, nullptr);
  xTaskCreate(&tplp::led_task, "led", 1024, nullptr, 2, nullptr);
  xTaskCreate(&tplp::stats_task, "stats", 1024, nullptr, 2, nullptr);
  vTaskStartScheduler();
  return 0;
}

}  // namespace tplp

int main() { return tplp::main(); }

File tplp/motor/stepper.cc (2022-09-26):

#include "tplp/motor/stepper.h"

#include <numeric>
#include <optional>

#include "FreeRTOS/FreeRTOS.h"
#include "FreeRTOS/task.h"
#include "hardware/clocks.h"
#include "hardware/gpio.h"
#include "hardware/pio.h"
#include "hardware/timer.h"
#include "pico/time.h"
#include "picolog/picolog.h"
#include "tplp/clkdiv.h"
#include "tplp/motor/sin_table.h"
#include "tplp/motor/stepper.pio.h"
#include "tplp/numbers.h"
#include "tplp/rtos_util.h"

namespace tplp {
namespace {
uint32_t make_command(uint8_t pwm_period, uint8_t t1, uint8_t t2_t3,
                      uint8_t pins_t2_t3, uint8_t pins_t4) {
  CHECK_GE(pwm_period, t1);
  CHECK_GE(t1, t2_t3);
  return (pwm_period << 0) | (t1 << 8) | (t2_t3 << 16) | (pins_t2_t3 << 24) |
         (pins_t4 << 28);
}

uint16_t ComputeWrap(int32_t hz) {
  static const auto sys_hz = clock_get_hz(clk_sys);
  // 256 is the value we set as the PWM's clock divider during init.
  // Multiply by an additional 2 because in phase-correct mode the
  // PWM counts both up and back down to 0 before each DREQ.
  uint32_t wrap = sys_hz / (std::abs(hz) * 256 * 2);
  if (wrap > 65535) wrap = 65535;
  return wrap;
}

}  // namespace

std::optional<int> StepperMotor::pio0_program_offset_ = std::nullopt;
std::optional<int> StepperMotor::pio1_program_offset_ = std::nullopt;
bool StepperMotor::static_init_done_ = false;

uint16_t StepperMotor::pio_pwm_period_ = 0;
int StepperMotor::pio_clkdiv_int_ = 0;
int StepperMotor::pio_clkdiv_frac_ = 0;
int StepperMotor::pio_hz_ = 0;
uint32_t StepperMotor::shortbrake_command_ = 0;
uint32_t StepperMotor::commands_fwd_[kCommandBufLen] = {};
uint32_t StepperMotor::commands_rev_[kCommandBufLen] = {};

StepperMotor::StepperMotor()
    : current_dma_(DmaController::TransferHandle::Invalid()) {}

int32_t StepperMotor::min_microstep_hz() {
  static const auto sys_hz = clock_get_hz(clk_sys);
  // 256 is the value we set as the PWM's clock divider during init.
  // 65535 is the maximum value of the TOP register (aka wrap).
  // Multiply by an additional 2 because in phase-correct mode the
  // PWM counts up to TOP and back down to 0 before each DREQ.
  return sys_hz / (65535 * 256 * 2);
}

int32_t StepperMotor::max_microstep_hz() {
  static const auto sys_hz = clock_get_hz(clk_sys);
  // 256 is the value we set as the PWM's clock divider during init.
  // When wrap is set to zero, the PWM generates a DREQ every cycle.
  return sys_hz / 256;
}

void StepperMotor::Move(int32_t new_microstep_hz) {
  VLOG(2) << "Move(" << new_microstep_hz << ")";
  if (new_microstep_hz == microstep_hz_) {
    // No change; nothing to do.
    return;
  } else if (new_microstep_hz == 0) {
    pwm_set_enabled(pwm_slice_num_, false);
    microstep_hz_ = 0;
    VLOG(1) << "DISABLE PWM";
  } else if (util::signum(new_microstep_hz) == current_dma_signum_) {
    uint32_t wrap = ComputeWrap(new_microstep_hz);
    pwm_set_wrap(pwm_slice_num_, wrap);
    pwm_set_enabled(pwm_slice_num_, true);
    VLOG(1) << "old_hz = " << microstep_hz_ << " new_hz = " << new_microstep_hz
            << " new_wrap = " << wrap << " SET WRAP";
    microstep_hz_ = new_microstep_hz;
  } else {
    // new_microstep_hz is nonzero and the direction doesn't match the current
    // dma. Pause everything and save the dma's read index.
    pwm_set_enabled(pwm_slice_num_, false);
    const uint32_t last_dma_trans_count = current_dma_.Abort()[0];
    const uint32_t last_dma_num_commands_sent =
        kInitialTransCount - last_dma_trans_count;
    microstep_counter_ += current_dma_signum_ * last_dma_num_commands_sent;
    last_dma_read_index_ =
        (last_dma_read_index_ + last_dma_num_commands_sent) % kCommandBufLen;
    microstep_hz_ = 0;

    // Start new dma in the opposite direction
    VLOG(1) << "CHANGE DIRECTION: "
            << " prev dma signum = " << current_dma_signum_
            << " new dma signum = " << util::signum(new_microstep_hz)
            << " last_dma_num_commands_sent = " << last_dma_num_commands_sent
            << " last_dma_read_index_ = " << last_dma_read_index_
            << " read_addr = commands + "
            << (kCommandBufLen - last_dma_read_index_ - 1);
    uint32_t* read_addr;
    last_dma_read_index_ = kCommandBufLen - last_dma_read_index_ - 1;
    if (new_microstep_hz > 0) {
      read_addr = commands_fwd_ + last_dma_read_index_;
    } else {
      read_addr = commands_rev_ + last_dma_read_index_;
    }
    current_dma_ = dma_->Transfer(MakeDmaRequest(read_addr));
    current_dma_signum_ = util::signum(new_microstep_hz);

    // Update speed and re-enable PWM
    uint16_t wrap = ComputeWrap(new_microstep_hz);
    pwm_set_wrap(pwm_slice_num_, wrap);
    VLOG(1) << "old_hz = " << microstep_hz_ << " new_hz = " << new_microstep_hz
            << " new_wrap = " << wrap;
    microstep_hz_ = new_microstep_hz;
    pwm_set_enabled(pwm_slice_num_, true);
  }
}

int32_t StepperMotor::GetPosition() const {
  return microstep_counter_ +
         current_dma_signum_ *
             (kInitialTransCount - current_dma_.trans_count()[0]);
}

void StepperMotor::SetPosition(int32_t position) {
  microstep_counter_ = position - microstep_counter_;
}

void StepperMotor::Stop() {
  VLOG(1) << "STOP";
  Move(0);
  uint32_t idx = (last_dma_read_index_ +
                  current_dma_signum_ *
                      (kInitialTransCount - current_dma_.trans_count()[0])) %
                 kCommandBufLen;
  if (current_dma_signum_ > 0) {
    *txf_ = commands_fwd_[idx];
  } else if (current_dma_signum_ < 0) {
    *txf_ = commands_rev_[idx];
  }
}

void StepperMotor::Release() {
  VLOG(1) << "RELEASE";
  Move(0);
  *txf_ = shortbrake_command_;
}
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

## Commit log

2022-07-21 work in progress
    i think this crappy little lcd panel may have kicked the bucket
2022-07-21 holy shit pico-arduino-compat is NOT worth it!!!!!
    what a MESS! i give up trying to make it build in a sane way.
2022-07-22 whee! DMA is Fun(tm)
    at least now the idle task can get some love
2022-07-28 Enable SMP :)
    ... and fix thread_local.h. How embarrassing.
    [main.cc]
2022-07-28 fix more thread-unsafe stdio usage
    [main.cc]
2022-07-29 tentatively, enable SMP and fix "everything"
    Friendship ended with fmtlib >:(
    [main.cc]
2022-07-30 use pico-sdk stack guards
2022-08-03 [WIP] broken SpiManager rewrite
    currently suspect the SpiTransaction move constructor (?)
    [main.cc]
2022-08-03 don't use thread_local
2022-08-07 clean up .bazelrc a bit by moving pico-sdk config
2022-08-09 move sdl stuff to main thread for macos
2022-08-11 HX8357 lvgl driver
2022-08-11 KittenUI™
2022-08-11 tighten up stack a little
2022-08-12 pins for I2C
    We can't use UART anymore because both peripheral slots (0 and 1) are
    now taken.
2022-08-12 start work on I2cController
2022-08-13 transactional interface for I2cController
2022-08-13 this needs to be shared now, with I2C
2022-08-13 DMA for I2C reads
2022-08-14 TSC2007 now with touch interrupt
2022-08-14 Added i2c device list template setting
2022-08-14 Added gap to button
2022-08-14 fix HX8357 flaky bootup
    [main.cc]
2022-08-15 screw those other stepper drivers!
2022-08-17 make i2c optional (for testing)
2022-08-17 just finished DmaController and already its replacement is on the way, SMH
    [I2cController.cc, SpiController.cc]
2022-08-20 [BROKEN] try to use new dma
    it's too complicated. i went overboard.
    [SpiController.cc]
2022-08-20 Revert "[BROKEN] try to use new dma"
    This reverts commit f05d02aee2d143c6125c12eee5201fbc680aa0aa.
    [SpiController.cc]
2022-08-20 Revert "ok but 20us is a long time to spend in an ISR"
    This reverts commit 8cc92983a98a937924c120394e05ced785a04592.
    [SpiController.cc, main.cc]
2022-08-22 I2cController to use DmaController
2022-08-24 wire up hx711
2022-08-25 add load cell testing bracket model
    [loadcell-testing-bracket.3mf, loadcell-testing-bracket.FCStd]
2022-08-25 add CAD files (imported from fusion360)
    [ftheta-lens-mount.FCStd, loadcell-mount-and-roller.FCStd, mirror-assembly.FCStd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]
2022-08-26 i2c a lil flaky sometimes
2022-08-26 HX711 driver. proud of this one :)
2022-08-26 Added load cell calibration UI
2022-08-26 add lens cap model
    [lens-cap.3mf, lens-cap.FCStd]
2022-08-26 wasn't actually using that pin
2022-08-27 sloppily disable these debug prints
2022-08-27 Added stepper motor settings
2022-08-29 thinking about motors
2022-08-29 add seesaw driver stub
2022-08-29 implement encoder wheel (but not button)
2022-08-29 encoder is flaky as fuck!!! what the hell!
2022-08-29 Added inc/dec buttons to stepper settings
2022-08-29 add stepper hardware
2022-08-29 Added LEDS for steppers
2022-08-29 Added load cell graph to stepper settings
2022-08-29 Removed test settings page; added icon to steppers page
2022-08-30 holey shite it's a sine wave
2022-08-31 is it DMA time yet?
2022-09-01 hooray! dma steppies! i feel so proud
2022-09-01 start on the ui hooks for stepper control
2022-09-07 move stepper pwm freq to hw.h
2022-09-09 note future pin needs
2022-09-09 switch to uart for debug output
2022-09-10 make DmaController thread-safe (by blunt force)
2022-09-14 add persistent flags framework
2022-09-17 replace UI main menu with a smaller lighter one
    [main.cc]
2022-09-18 add load cell zeroing button
2022-09-18 holy shitballs!! basic paper tensioning!!
2022-09-18 implement timer-based slow speed for steppers
2022-09-18 increase irq priority for steppers
2022-09-19 add timer interrupt to paper controller
2022-09-19 fix stepper timer irq logic
    [paper_controller.cc, stepper.cc]
2022-09-19 redesign stepper api
2022-09-20 make StepperMotor statically allocated
2022-09-22 back to DMA for the steppers! reverse still buggy
    [TplpInterfaceImpl.cc, paper_controller.cc, stepper.cc]
2022-09-22 use phase-correct mode for even slower min speed
    [stepper.cc]
2022-09-23 motors fixed! we're tuning pid now :)
    [TplpInterfaceImpl.cc, paper_controller.cc, stepper.cc]
2022-09-23 track nominal stepper position
2022-09-23 add stepper position to ui
2022-09-24 screwing around with pid stuff. yay ~numbers~
2022-09-28 cad: clean out old junk, add new parts
    [Encoder mount v3.step, Encoder mount.stl, Stepper mount v3.step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]
2022-09-28 add speculative parts for paper system redesign
    [bare-24.stl, bearing seat 608 v3.step, bearing seat 608.stl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]
2022-09-28 more cad work
    [Encoder mount v3.step, Encoder mount v4.step, Encoder mount.stl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]
2022-09-30 add dcmotor pulley
    [dcmotor-12.stl, steppermotor-12.stl, steppermotor-24.stl]
